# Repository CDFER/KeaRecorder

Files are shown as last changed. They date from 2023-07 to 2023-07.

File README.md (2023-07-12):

# KeaRecorder



Welcome to KeaRecorder! This device allows you to accurately record ground water temperature using the ESP32S2 microcontroller.
## Table of Contents

- [KeaRecorder](#kearecorder)
  - [Table of Contents](#table-of-contents)
  - [Overview](#overview)
  - [Main Hardware Components](#main-hardware-components)
  - [Usage](#usage)
  - [Installation](#installation)
  - [Configuration](#configuration)
  - [Contributing](#contributing)
  - [Other](#other)
  - [License](#license)

## Overview

KeaRecorder is an designed specifically for recording and monitoring ground water temperature. Here are some key features of KeaRecorder:

- Backup clock: The built-in backup clock ensures accurate timekeeping, even when far away from civilization, guaranteeing reliable temperature data.
- Timezone support: Customize the time display and recordings based on your location, allowing seamless integration into your local time zone.
- Wi-Fi time synchronization: KeaRecorder synchronizes its time through a Wi-Fi network time server, providing accurate time information for precise temperature monitoring.
- Low power consumption: With its energy-efficient design, KeaRecorder can operate for extended periods without draining the battery.
- Easy access to data: KeaRecorder emulates a USB drive through its USB-C port, simplifying access to temperature data stored on the SD card.

## Main Hardware Components

KeaRecorder utilizes high-quality hardware components to ensure optimal performance and reliability. Here are the main hardware components used:

- SLM6500 Lithium ion BMS: This Battery Management System ensures safe and efficient operation, managing power effectively.
- ESP32S2: The ESP32S2 microcontroller provides the necessary processing power and connectivity options, serving as the brain of KeaRecorder.
- MicroSD card (SPI): The SD card securely stores the recorded temperature data, offering ample storage capacity for monitoring needs.
- ST7789V3 IPS Display (SPI): The vibrant display module shows real-time temperature readings from the sensors in vivid detail.
- PCF8563 RTC (I2C): The Real-Time Clock (RTC) module enables precise timekeeping, ensuring accurate temperature records.
- 3 OneWire Busses with up to 5 DS18B20 Temperature Sensors on each: These temperature sensors allow monitoring of multiple areas or depths with ease and accuracy.

## Usage

Using KeaRecorder is easy and intuitive. Follow these steps to get started:

1. Power on the KeaRecorder unit by pressing the button to activate the display.
2. The display will show real-time temperature readings obtained from the sensors, providing instant insights into ground water temperature.
3. Press and hold the button to toggle the recording mode. This enables or disables the logging of temperature readings to the SD card at regular intervals, according to your needs.
4. Once recording is enabled, KeaRecorder will diligently capture and log temperature data, ensuring comprehensive records of ground water temperature fluctuations.
5. To access the recorded temperature data, either remove the SD card from KeaRecorder and insert it into a computer or connect KeaRecorder to a computer using a USB cable.





## Installation

Installing KeaRecorder is a straightforward process. Just follow these steps:

1. Clone the repository to your local machine to access the latest version of the code.
2. If you're using PlatformIO, the required libraries will be installed automatically. If not, make sure to manually install the necessary libraries.
3. Compile the code and upload it to the ESP32 device.

## Configuration

You can customize KeaRecorder using the following configuration options:

- WiFi Credentials: Update the `main.cpp` file with your WiFi network name and password to seamlessly integrate KeaRecorder into your existing network.
- Recording Interval: Adjust the `recordingIntervalMins` variable to set the desired interval for recording temperature readings. This allows you to tailor the device's logging frequency to your specific monitoring requirements.
- Time Zone: Modify the `time_zone` variable to establish the desired time zone, ensuring accurate time display and recording based on your location.

## Contributing

We welcome contributions from the community! Here's how you can contribute to the project's ongoing development:

1. Fork the repository to create a personal copy of the project.
2. Create a new branch dedicated to your feature or bug fix, ensuring focused and organized contributions.
3. Implement the necessary changes and commit your code, including clear and concise documentation.
4. Push the changes to your forked repository, making them available for further review and integration.
5. Submit a pull request to the main repository, allowing your contributions to be considered for inclusion in the project.

## Other

Special thanks to the exceptional team at @Espressif Systems for their remarkable work in developing this outstanding chip and seamlessly porting it to Arduino.

Made with passion and dedication by Chris Dirks (@cd_fer) in Aotearoa New Zealand.

## License

KeaRecorder is proudly licensed under the Hippocratic License HL3-CL-EXTR-FFD-MEDIA-MIL-MY-SV-TAL. For detailed licensing terms, please review the license file provided.

Feel free to reach out if you have any questions or need further assistance. Happy monitoring with KeaRecorder!

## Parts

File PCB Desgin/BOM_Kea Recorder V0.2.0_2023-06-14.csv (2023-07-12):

ID | Name | Designator | Footprint | Quantity | Manufacturer Part | Manufacturer | Supplier | Supplier Part | Price | Pins | JLCPCB Part Class | Contributor | Resistance (Ohms) | link
3 | 100nF | C1,C2,C7,C9,C13,C17,C22,C29,C30,C32,C33,C34,C35,C37,C38,C39 | C0402 | 16 | CL05B104KO5NNNC | SAMSUNG(三星) | LCSC | C1525 | 0.001 | 2 | Basic Part
4 | 10uF | C3,C5,C12,C14,C16,C18,C19,C21,C23,C40 | C0402 | 10 | CL05A106MQ5NUNC | SAMSUNG(三星) | LCSC | C15525 | 0.005 | 2 | Basic Part
5 | 22uF | C4 | C0603 | 1 | CL10A226MQ8NRNC | SAMSUNG(三星) | LCSC | C59461 | 0.01 | 2 | Basic Part
6 | 4.7uF | C6,C20,C24 | C0402 | 3 | CL05A475MP5NRNC | SAMSUNG(三星) | LCSC | C23733 | 0.006 | 2 | Basic Part
7 | 1uF | C8,C31,C36 | C0402 | 3 | CL05A105KA5NQNC | SAMSUNG(三星) | LCSC | C52923 | 0.004 | 2 | Basic Part
8 | 22pF | C15 | C0402 | 1 | 0402CG220J500NT | FH(风华) | LCSC | C1555 | 0.001 | 2 | Basic Part
9 | 4.7pF | C41 | C0402 | 1 | 0402CG4R7C500NT | FH(风华) | LCSC | C1569 | 0.001 | 2 | Basic Part
10 | 27pF | C42,C43 | C0402 | 2 | 0402CG270J500NT | FH(风华) | LCSC | C1557 | 0.001 | 2 | Basic Part
11 | 2.7pF | C44 | C0402 | 1 | 0402CG2R7C500NT | FH(风华) | LCSC | C1561 | 0.001 | 2 | Basic Part
12 | 1pF | C45 | C0402 | 1 | 0402CG1R0C500NT | FH(风华) | LCSC | C1550 | 0.001 | 2 | Basic Part
13 | SMF30CA | D1 | SOD-123FL_L2.8-W1.8-LS3.7-BI | 1 | SMF30CA | Liown(里阳半导体) | LCSC | C2990493 | 0.034 | 2 | Basic Part | lcsc |  | https://atta.szlcsc.com/upload/public/pdf/source/20220523/073C11711A077522E04B0931D8CF3CC3.pdf
14 | 1N5819WS | D2 | SOD-323_L1.8-W1.3-LS2.5-RD | 1 | 1N5819WS | Hottech(合科泰) | LCSC | C191023 | 0.014 | 2 | Basic Part | LCSC
15 | 1N4148 | D3 | SOD-323_L1.8-W1.3-LS2.5-RD | 1 | 1N4148WS | CJ(江苏长电/长晶) | LCSC | C2128 | 0.01 | 2 | Basic Part
16 | ZMM3V3 | D4 | LL-34_L3.5-W1.5-RD | 1 | ZMM3V3-M | ST(先科) | LCSC | C8056 | 0.012 | 2 | Basic Part
17 | SRV05-4-P-T7 | ESD1 | SOT-23-6_L2.9-W1.6-P0.95-LS2.8-BR | 1 | SRV05-4-P-T7 | PROTEK | LCSC | C85364 | 0.176 | 6 | Basic Part
18 | 2A Hold 4A Trip Resettable Fuse | F1,F2 | F0805 | 2 | SL0805200 | 台湾陆海 | LCSC | C70158 | 0.069 | 2 | Extended Part
19 | OWBUS1 | JST1 | CONN-SMD_4P-P1.00_DEALON_1.0-4PWB | 1 | 1.0-4PWB | DEALON(德艺隆) | LCSC | C2905006 | 0.035 | 6 | Extended Part | LCSC
20 | OWBUS2 | JST2 | CONN-SMD_4P-P1.00_DEALON_1.0-4PWB | 1 | 1.0-4PWB | DEALON(德艺隆) | LCSC | C2905006 | 0.035 | 6 | Extended Part | LCSC
21 | OWBUS3 | JST3 | CONN-SMD_4P-P1.00_DEALON_1.0-4PWB | 1 | 1.0-4PWB | DEALON(德艺隆) | LCSC | C2905006 | 0.035 | 6 | Extended Part | LCSC
22 | UART | JST4 | CONN-SMD_4P-P1.00_DEALON_1.0-4PWB | 1 | 1.0-4PWB | DEALON(德艺隆) | LCSC | C2905006 | 0.035 | 6 | Extended Part | LCSC
23 | 3.3uH, 6A | L1 | IND-SMD_L7.3-W6.8 | 1 | MCS0630-3R3MN2 | PSA(信昌电陶) | LCSC | C394166 | 0.051 | 2 | Extended Part | LCSC
24 | 3.9nH 300mA | L2,L3 | C0402 | 2 | SDCL1005C3N9STDF | Sunlord(顺络) | LCSC | C14033 | 0.003 | 2 | Basic Part
25 | 3.9nH | L4,L5 | C0402 | 2 | SDCL1005C3N9STDF | Sunlord(顺络) | LCSC | C14033 | 0.003 | 2 | Basic Part
26 | 1.47"-IPS-LCD-172X320-RGB | LCD1 | 1.47"-IPS-TFT-172X320-RGB | 1 |  |  | ZJY |  |  | 12 |  | Mingjie
27 | ESP32PWR | LDO1 | SOT-25-5_L3.0-W1.8-P0.95-LS3.0-BR | 1 | XC6220B331MR-G | TOREX(特瑞仕) | LCSC | C86534 | 0.368 | 5 | Extended Part
28 | IOPWR | LDO2 | SOT-25-5_L3.0-W1.8-P0.95-LS3.0-BR | 1 | XC6220B331MR-G | TOREX(特瑞仕) | LCSC | C86534 | 0.368 | 5 | Extended Part
29 | SPIPWR | LDO3 | SOT-25-5_L3.0-W1.8-P0.95-LS3.0-BR | 1 | XC6220B331MR-G | TOREX(特瑞仕) | LCSC | C86534 | 0.368 | 5 | Extended Part
30 | CHRG | LED1 | LED0603-RD | 1 | KT-0603R | null | LCSC | C2286 | 0.006 | 2 | Basic Part
31 | STDBY | LED2 | LED0603-RD | 1 | 19-217/GHC-YR1S2/3T | EVERLIGHT(亿光) | LCSC | C72043 | 0.027 | 2 | Basic Part
32 | OCP Fault | LED3 | LED0603-RD | 1 | KT-0603R | null | LCSC | C2286 | 0.006 | 2 | Basic Part
33 | TX | LED4 | LED0603-RD | 1 | 19-213/Y2C-CQ2R2L/3T(CY) | EVERLIGHT(亿光) | LCSC | C72038 | 0.023 | 2 | Basic Part
34 | RX | LED5 | LED0603-RD | 1 | 19-213/Y2C-CQ2R2L/3T(CY) | EVERLIGHT(亿光) | LCSC | C72038 | 0.023 | 2 | Basic Part
35 | UART_TX | LED6 | LED0603-RD | 1 | 19-213/Y2C-CQ2R2L/3T(CY) | EVERLIGHT(亿光) | LCSC | C72038 | 0.023 | 2 | Basic Part
36 | UART_RX | LED7 | LED0603-RD | 1 | 19-213/Y2C-CQ2R2L/3T(CY) | EVERLIGHT(亿光) | LCSC | C72038 | 0.023 | 2 | Basic Part
37 | 100k NTC Thermistor (B=4250) | NTC1 | R0402 | 1 | NCP15WF104F03RC | muRata(村田) | LCSC | C77130 | 0.013 | 2 | Extended Part
38 | AO3401A (PMOS) | Q1 | SOT-23_L2.9-W1.3-P1.90-LS2.4-BR | 1 | AO3401A | AOS | LCSC | C15127 | 0.042 | 3 | Basic Part
39 | 2N7002 | Q2 | SOT-23-3_L2.9-W1.3-P1.90-LS2.4-BR | 1 | 2N7002 | CJ(江苏长电/长晶) | LCSC | C8545 | 0.015 | 3 | Basic Part
40 | PNP (MMBT5401) | Q3 | SOT-23-3_L2.9-W1.3-P1.90-LS2.4-BR | 1 | MMBT5401 | CJ(江苏长电/长晶) | LCSC | C8326 | 0.015 | 3 | Basic Part | 立创EDA官方封装库
41 | 5.1kΩ | R1,R2 | R0402 | 2 | 0402WGF5101TCE | UNI-ROYAL(厚声) | LCSC | C25905 | 0.001 | 2 | Basic Part |  | 5.1K
42 | 10kΩ | R3,R9,R11,R14,R15,R16,R26,R27 | R0402 | 8 | 0402WGF1002TCE | UNI-ROYAL(厚声) | LCSC | C25744 | 0.001 | 2 | Basic Part |  | 10K
43 | 100kΩ | R4,R8,R10,R21,R22,R25,R28,R34,R39,R41 | R0402 | 10 | 0402WGF1003TCE | UNI-ROYAL(厚声) | LCSC | C25741 | 0.001 | 2 | Basic Part |  | 100K
44 | 100mΩ | R5,R7 | R1206 | 2 | 1206W4F100LT5E | UNI-ROYAL(厚声) | LCSC | C25334 | 0.007 | 2 | Basic Part |  | 0.1
45 | 150kΩ | R6 | R0402 | 1 | 0402WGF1503TCE | UNI-ROYAL(厚声) | LCSC | C25755 | 0.001 | 2 | Basic Part |  | 150K
46 | 1MΩ | R12,R13,R19,R20 | R0402 | 4 | 0402WGF1004TCE | UNI-ROYAL(厚声) | LCSC | C26083 | 0.001 | 2 | Basic Part |  | 1M
47 | 4.7kΩ | R17,R18 | R0402 | 2 | 0402WGF4701TCE | UNI-ROYAL(厚声) | LCSC | C25900 | 0.001 | 2 | Basic Part |  | 4.7K
48 | 0Ω | R23 | R0402 | 1 | 0402WGF0000TCE | UNI-ROYAL(厚声) | LCSC | C17168 | 0.001 | 2 | Basic Part |  | 0
49 | 470Ω | R24 | R0402 | 1 | 0402WGF4700TCE | UNI-ROYAL(厚声) | LCSC | C25117 | 0.001 | 2 | Basic Part |  | 470
50 | 47kΩ | R29,R30,R31,R32,R38,R40,R44,R45 | R0402 | 8 | 0402WGF4702TCE | UNI-ROYAL(厚声) | LCSC | C25792 | 0.001 | 2 | Basic Part |  | 47K
51 | 200Ω | R33 | R0402 | 1 | 0402WGF2000TCE | UNI-ROYAL(厚声) | LCSC | C25087 | 0.001 | 2 | Basic Part |  | 200
52 | 10Ω | R35 | R0402 | 1 | 0402WGF100JTCE | UNI-ROYAL(厚声) | LCSC | C25077 | 0.001 | 2 | Basic Part |  | 10
53 | 4.7kΩ | R36,R37,R42 | R0805 | 3 | 0805W8F4701T5E | UNI-ROYAL(厚声) | LCSC | C17673 | 0.002 | 2 | Basic Part |  | 4.7K
54 | 33kΩ | R43 | R0402 | 1 | 0402WGF3302TCE | UNI-ROYAL(厚声) | LCSC | C25779 | 0.001 | 2 | Basic Part |  | 33K
55 | TF-01A | SD1 | TF-SMD_TF-01A | 1 | TF-01A | 韩国韩荣 | LCSC | C91145 | 0.175 | 13 | Extended Part
56 | RESET | SW1 | KEY-SMD_4P-L4.2-W3.2-P2.20-LS4.6 | 1 |  |  |  |  |  | 4 |  | LCSC
57 | UP | SW2 | KEY-SMD_4P-L4.2-W3.2-P2.20-LS4.6 | 1 |  |  |  |  |  | 4 |  | LCSC
58 | DOWN | SW3 | KEY-SMD_4P-L4.2-W3.2-P2.20-LS4.6 | 1 |  |  |  |  |  | 4 |  | LCSC
59 | WAKE | SW4 | SW-TH_4P-L12.0-W12.0-P5.00-LS12.5-EH | 1 | SKHCBGA010 | ALPSALPINE(阿尔卑斯阿尔派) |  |  |  | 4 | Extended Part | LCSC
72 | GT-USB-7010ASV | U1 | USB-C-SMD_G-SWITCH_GT-USB-7010ASV | 1 | GT-USB-7010ASV | G-Switch(品赞) | LCSC | C2988369 | 0.079 | 16 | Extended Part | lcsc |  | https://atta.szlcsc.com/upload/public/pdf/source/20220407/276C2E8CEADC75D1A3BE3EA4074DCCE5.pdf
73 | SLM6500 | U2 | SOP-8_L4.9-W3.9-P1.27-LS6.0-BL-EP | 1 | SLM6500 | 无锡松朗微 | LCSC | C130315 | 0.241 | 9 | Extended Part | LCSC
74 | BWU.FL-IPEX1 | U3 | IPEX-SMD_BWIPX-1-001E | 1 | BWU.FL-IPEX1 | BAT WIRELESS(蝙蝠无线) | LCSC | C5137195 | 0.035 | 3 | Extended Part | lcsc |  | https://atta.szlcsc.com/upload/public/pdf/source/20220815/058ABE525AAE400925F1A3839AB872AC.pdf
75 | PCF8563T RTC | U4 | SOIC-8_L5.0-W4.0-P1.27-LS6.0-BL | 1 | PCF8563T/5,518 | NXP(恩智浦) | LCSC | C7440 | 0.485 | 8 | Basic Part
76 | ESP32-S2FN4R2 | U5 | QFN-56_L7.0-W7.0-P0.40-TL-EP4.0 | 1 | ESP32-S2FN4R2 | ESPRESSIF(乐鑫) | LCSC | C2844252 | 1.82 | 57 | Extended Part | LCSC
77 | 32.768kHz | X1 | FC-135R_L3.2-W1.5 | 1 | Q13FC1350000400 | EPSON(爱普生) | LCSC | C32346 | 0.199 | 2 | Basic Part
78 | 40MHz 15pF ±10ppm | X2 | CRYSTAL-SMD_4P-L3.2-W2.5-BL | 1 | S3240000151040 | JGHC(晶光华) | LCSC | C426990 | 0.065 | 4 | Extended Part | LCSC

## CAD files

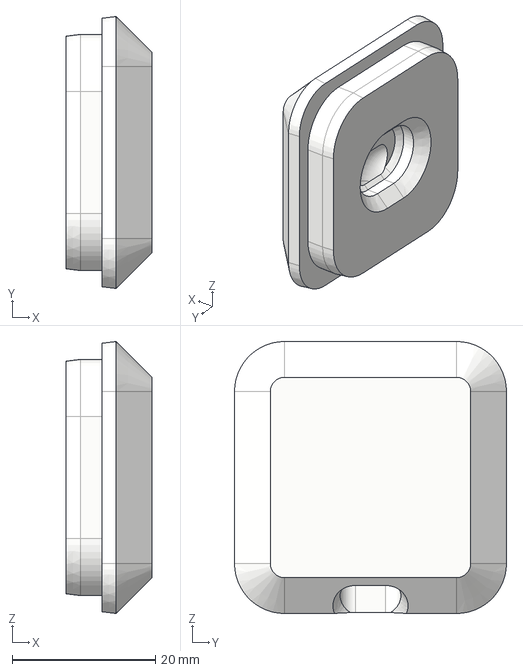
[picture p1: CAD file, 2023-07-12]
3D Printed Case/Connector v6.step
12.0 x 38.0 x 38.0 mm

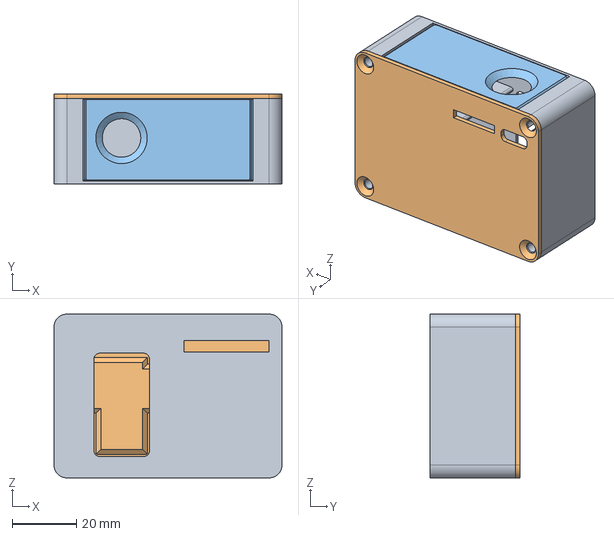
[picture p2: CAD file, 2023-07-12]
3D Printed Case/keaRecorder0.2.0 v22.step
71.0 x 28.1 x 51.0 mm

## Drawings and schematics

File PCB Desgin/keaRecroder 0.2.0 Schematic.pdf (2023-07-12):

# Lithium Battery Charger

# USB INPUT

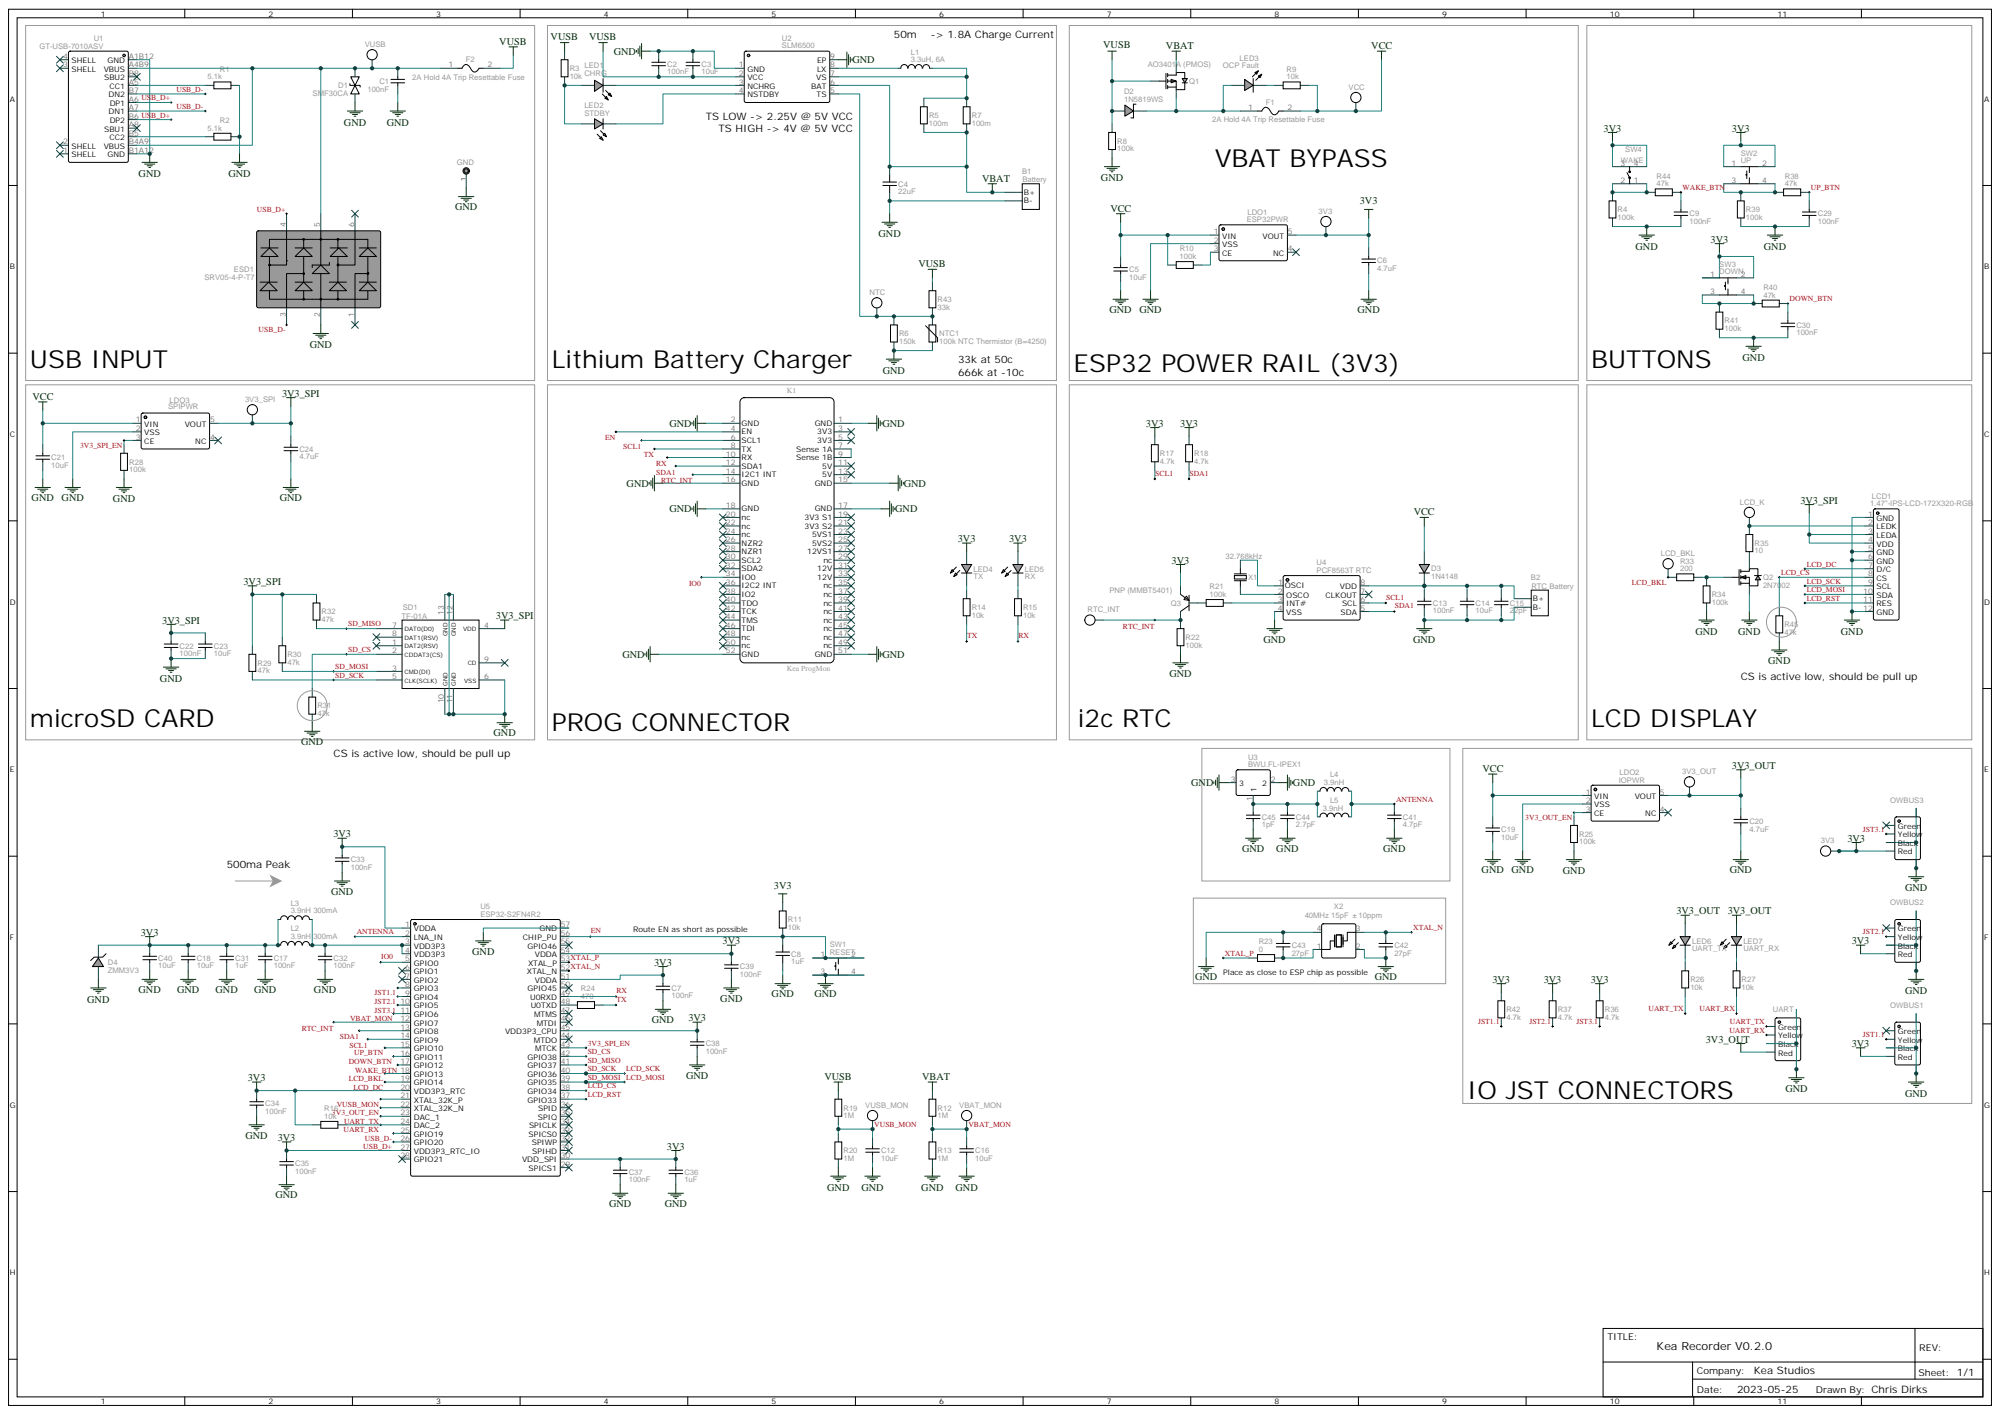
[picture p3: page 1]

2A Hold 4A Trip Resettable Fuse

GND
CS is active low, should be pull up

SPICS1 29 VDD_SPI 30 SPIHD 31 SPIWP 32 SPICS0 33 SPICLK 34 SPIQ 35 SPID 36 GPIO33 37 GPIO34 38 GPIO35 39 GPIO36 40 GPIO37 41 GPIO38 42 MTCK 43 MTDO 44 VDD3P3_CPU 45 MTDI 46 MTMS 47 U0TXD 48 U0RXD 49 GPIO45 50 VDDA 51 XTAL_N 52 XTAL_P 53 VDDA 54 GPIO46 55 CHIP_PU 56 GND 57

Place as close to ESP chip as possible

Drawn By: Chris Dirks

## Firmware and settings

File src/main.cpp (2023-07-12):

#include <Arduino.h>
#include <DallasTemperature.h>
#include <OneWire.h>
#include <SD.h>
#include <WiFi.h>
#include <tft_eSPI.h>

#include "USB.h"
#include "USBMSC.h"
#include "credentials.h"
#include "pcf8563.h"
#include "sntp.h"
#include "time.h"

#ifndef CREDENTIALS_H
#define CREDENTIALS_H

#define WIFI_WIFI_SSID "YourWIFI"
#define WIFI_PW "PASSWORD"

#endif

// Constants
constexpr uint8_t SCREEN_ON_TIME = 30;
constexpr uint16_t HOLD_DURATION = 3000;
constexpr uint8_t ONEWIRE_TEMP_RESOLUTION = 10;

const uint8_t batterySmoothingFactor = 5;	   // Example: 10 represents 10% of new value
const float temperatureSmoothingFactor = 0.5;  // Smaller values for slower response, larger values for faster response with more noise

// const char* time_zone = "NZST-12NZDT,M9.5.0,M4.1.0/3";
const char* time_zone = "CST6CDT,M3.2.0,M11.1.0";
constexpr uint32_t DEEPSLEEP_INTERUPT_BITMASK = (1UL << WAKE_BUTTON) | (1UL << VUSB_SENSE);
constexpr uint32_t RTC_DEEPSLEEP_INTERUPT_BITMASK = DEEPSLEEP_INTERUPT_BITMASK | (1UL << WIRE_RTC_INT);

// Ultra Global Variables (stored even in deep sleep)
RTC_DATA_ATTR uint16_t batteryMilliVolts = 0;
RTC_DATA_ATTR bool recording = false;
RTC_DATA_ATTR uint8_t recordingIntervalMins = 15;
RTC_DATA_ATTR char logFilePath[64];
RTC_DATA_ATTR char serialNumber[3];

// Global Variables
TFT_eSPI screen;
PCF8563_Class rtc;
bool systemTimeValid = false;
bool recordingDot = true;
bool sensorsChanged = false;

SemaphoreHandle_t buttonSemaphore;

USBMSC MSC;
USBCDC USBSerial;

auto configurePin = [](int pin, int mode, int initialState) {
	pinMode(pin, mode);
	digitalWrite(pin, initialState);
};

// For this to work with Espressif's ESP32 code you need to change line 694 esp32 / hardware / eps32 / 2.0.3 / libraries / SD / src / sd_diskio.cpp

static int32_t onWrite(uint32_t lba, uint32_t offset, uint8_t* buffer, uint32_t bufsize) {
	return SD.writeRAW((uint8_t*)buffer, lba) ? bufsize : -1;
}

static int32_t onRead(uint32_t lba, uint32_t offset, void* buffer, uint32_t bufsize) {
	return SD.readRAW((uint8_t*)buffer, lba) ? bufsize : -1;
}

static bool onStartStop(uint8_t power_condition, bool start, bool load_eject) {
	return true;
}

// Struct to hold information about a single temperature sensor
struct temperatureSensor {
	DeviceAddress address;
	float temperature;
	bool error;
};

// Struct to hold information about a temperature sensor bus
struct temperatureSensorBus {
	uint8_t numberOfSensors;
	uint8_t oneWirePin;
	OneWire oneWireBus;
	DallasTemperature dallasTemperatureBus;
	temperatureSensor sensorList[5];
	uint32_t color;
};

// Struct to hold information about the SD card
struct sdCard {
	uint16_t cardTotalMib;
	uint16_t cardUsedMib;
	const char* cardType;
	bool connected;
};

const uint8_t oneWirePortCount = 3;
RTC_DATA_ATTR temperatureSensorBus oneWirePort[oneWirePortCount];
RTC_DATA_ATTR sdCard microSDCard;

/**
 * @brief Extracts the first hex character from byte 1, 3, 5, and 7 of a DeviceAddress.
 *
 * This function takes a DeviceAddress, which is an array of bytes representing a device address,
 * and extracts the first hex character from bytes 1, 3, 5, and 7. The result is stored in a static
 * character array and returned. The result array is null-terminated.
 *
 * @param address The DeviceAddress from which to extract the hex characters.
 * @return A pointer to the static character array holding the extracted hex characters.
 */
char* deviceAddressTo4Char(const DeviceAddress& address) {
	static char result[5];	// Static array to hold the extracted hex characters
	result[4] = '\0';		// Null-terminate the result array

	// Define a lookup table for hex characters
	const char hexLookup[] = "0123456789ABCDEF";

	// Extract the hex characters from bytes 1, 3, 5, and 7
	result[0] = hexLookup[(address[1] >> 4) & 0x0F];
	result[1] = hexLookup[(address[3] >> 4) & 0x0F];
	result[2] = hexLookup[(address[5] >> 4) & 0x0F];
	result[3] = hexLookup[(address[7] >> 4) & 0x0F];

	return result;
}

/**
 * @brief Interrupt handler for the button press.
 *
 * This function is called when the button interrupt is triggered. It gives the button semaphore,
 * allowing the button task to proceed. It also yields to a higher priority task if necessary.
 */
void buttonInterrupt() {
	BaseType_t xHigherPriorityTaskWoken = pdFALSE;
	xSemaphoreGiveFromISR(buttonSemaphore, &xHigherPriorityTaskWoken);
	portYIELD_FROM_ISR(xHigherPriorityTaskWoken);
}

/**
 * @brief Get the current date and time as a formatted string.
 *
 * @param format The desired format of the date and time string.
 * @return The current date and time as a formatted string.
 */
const char* getCurrentDateTime(const char* format) {
	static char dateTime[32];
	time_t currentEpoch;
	time(&currentEpoch);
	struct tm* timeInfo = localtime(&currentEpoch);
	strftime(dateTime, sizeof(dateTime), format, timeInfo);
	return dateTime;
}

/**
 * @brief Sets up the next alarm based on the current time and recording interval.
 *
 * This function calculates the next alarm minute based on the current time and the specified
 * recording interval. If the current minute is not aligned with the recording interval, it
 * adjusts the alarm minute to align with the next interval. If the alarm minute exceeds 60,
 * it wraps around to the next hour. The alarm is then set using the calculated minute.
 * Additionally, the alarm, timer, and CLK are enabled, and a log message is printed.
 */
void setupNextAlarm() {
	RTC_Date currentTime = rtc.getDateTime();

	uint8_t alarmMinute = currentTime.minute;

	if (currentTime.minute % recordingIntervalMins != 0) {
		// The current minute is not aligned with the recording interval
		// Calculate the adjustment needed to align with the next interval
		alarmMinute += recordingIntervalMins - (currentTime.minute % recordingIntervalMins);
	} else {
		// The current minute is already aligned with the recording interval
		// Increment alarmMinute by the recording interval
		alarmMinute += recordingIntervalMins;
	}

	if (alarmMinute >= 60) {
		// Set alarmMinute to 0 to wrap around to the next hour
		alarmMinute = 0;
	}

	rtc.setAlarmByMinutes(alarmMinute);
	rtc.enableAlarm();
	rtc.disableTimer();
	rtc.disableCLK();

	ESP_LOGI("Setting Recording Alarm", "Next alarm: %u, Current minute: %u", alarmMinute, currentTime.minute);
}

/**
 * @brief Clears the RTC alarm.
 *
 */
void clearAlarm() {
	rtc.disableAlarm();
	rtc.disableTimer();
	rtc.disableCLK();
}

/**
 * @brief Gets the serial number based on the MAC address
 */
void getSerialNumber() {
	uint8_t mac[6];
	WiFi.macAddress(mac);
	sprintf(serialNumber, "%02X", mac[5]);
}

/**
 * @brief Generates a filename based on the current timestamp and MAC address.
 * @return The generated filename as a null-terminated string.
 */
void generateFilename() {
	// Get the serial number
	getSerialNumber();

	// Build the filename with leading forward slash
	snprintf(logFilePath, sizeof(logFilePath), "/%s_%s.csv", getCurrentDateTime("%Y-%b-%e-%H%M"), serialNumber);  // Format: /2023-Jun-23-2041_C8.csv

	File file = SD.open(logFilePath, FILE_WRITE, true);
	if (!file) {
		ESP_LOGW("generateFilename", "Failed to open file");
		return;
	}

	char header[128] = "Date(YYYY-MM-DD),Time(HH:MM),Battery(mV)";

	// Iterate over each temperature sensor bus
	for (uint8_t portIndex = 0; portIndex < oneWirePortCount; portIndex++) {
		if (oneWirePort[portIndex].numberOfSensors > 0) {
			// Iterate over each sensor on the current bus
			for (uint8_t sensorIndex = 0; sensorIndex < oneWirePort[portIndex].numberOfSensors; sensorIndex++) {
				// Convert the address to text
				char tempStr[8];
				snprintf(tempStr, sizeof(tempStr), ",%s", deviceAddressTo4Char(oneWirePort[portIndex].sensorList[sensorIndex].address));
				strcat(header, tempStr);
			}
		}
	}

	file.println(header);
	ESP_LOGD("", "%s", header);

	file.close();
}

/**
 * @brief Task that monitors the wake button and toggles recording mode.
 *
 * This task initializes the wake button pin, attaches an interrupt to detect rising edges,
 * and monitors the button state to toggle the recording mode. When the button is pressed
 * and held for a certain duration, the recording mode is toggled. If recording is enabled,
 * the next alarm is set. The task periodically checks the button state using a semaphore
 * and waits for interrupts to occur.
 *
 * @param parameter Pointer to the task parameters (not used in this implementation).
 */
void buttonTask(void* parameter) {
	// Initialize wake button pin and attach interrupt
	pinMode(WAKE_BUTTON, INPUT);
	attachInterrupt(digitalPinToInterrupt(WAKE_BUTTON), buttonInterrupt, RISING);

	buttonSemaphore = xSemaphoreCreateBinary();

	TickType_t lastWakeTime = xTaskGetTickCount();

	while (true) {
		if (xSemaphoreTake(buttonSemaphore, portMAX_DELAY) == pdTRUE) {
			if (digitalRead(WAKE_BUTTON) == HIGH) {
				vTaskDelay(pdMS_TO_TICKS(HOLD_DURATION));  // Delay for the hold duration

				if (digitalRead(WAKE_BUTTON) == HIGH) {
					if (recording) {
						recording = false;
						vTaskDelay(10000 / portTICK_PERIOD_MS);
					} else {
						recording = true;
						generateFilename();
						ESP_LOGI("Started New File", "%s", logFilePath);

						setupNextAlarm();
						vTaskDelay(10000 / portTICK_PERIOD_MS);
					}
				}
			} 
		}

		vTaskDelayUntil(&lastWakeTime, pdMS_TO_TICKS(10));	// Check every 10 milliseconds for interrupt semaphore
	}
}

/**
 * @brief Enters deep sleep mode based on battery voltage and recording status.
 *
 * If the battery voltage is above 3300 millivolts and recording is enabled, the function
 * enables deep sleep mode with RTC wakeup. Otherwise, it enables deep sleep mode with
 * wakeup triggered by user input. After setting up the wakeup mode, the function starts
 * the deep sleep process.
 */
void enterDeepSleep() {
	if ((batteryMilliVolts > 3300) && recording) {
		// Enable deep sleep mode with RTC wakeup
		esp_sleep_enable_ext1_wakeup(RTC_DEEPSLEEP_INTERUPT_BITMASK, ESP_EXT1_WAKEUP_ANY_HIGH);
		ESP_LOGV("Enter DeepSleep", "Waiting For RTC or user input");
	} else {
		// Enable deep sleep mode with wakeup triggered by user input
		esp_sleep_enable_ext1_wakeup(DEEPSLEEP_INTERUPT_BITMASK, ESP_EXT1_WAKEUP_ANY_HIGH);
		ESP_LOGI("Enter DeepSleep", "Waiting for user input");
	}

	// Start the deep sleep process
	esp_deep_sleep_start();

	// code here will never be run...
}

/**
 * @brief Updates the clock based on the current system time or using NTP servers.
 *
 * This function initializes the RTC module and syncs it to the system time if recording is enabled.
 * If recording is disabled or the system time is not valid, the function syncs the RTC using NTP servers.
 * The function also sets up the next alarm if recording is enabled and the RTC interrupt pin is in the HIGH state.
 */
void updateClock() {
	Wire.begin(WIRE_SDA, WIRE_SCL, 100000);
	rtc.begin(Wire);

	// Sync RTC to the system time if available
	if (rtc.syncToSystem()) {
		setenv("TZ", time_zone, 1);
		tzset();
		systemTimeValid = true;
	} else {
		ESP_LOGE("Time", "NOT VALID");
		systemTimeValid = false;
	}

	pinMode(WIRE_RTC_INT, INPUT);

	if (recording) {
		// Setup the next alarm if the RTC interrupt pin is in the HIGH state
		if (digitalRead(WIRE_RTC_INT) == HIGH) {
			setupNextAlarm();
		}
	} else {
		if (digitalRead(WIRE_RTC_INT) == HIGH) {
			clearAlarm();
		}

		if (!systemTimeValid) {
			// Sync RTC using WIFI and NTP servers if system time is not valid

			// Define the NTP servers to be used for time synchronization
			const char* ntpServer1 = "pool.ntp.org";
			const char* ntpServer2 = "time.nist.gov";
			const char* ntpServer3 = "time.google.com";

			// Set the SNTP operating mode to polling, and configure the NTP servers
			sntp_setoperatingmode(SNTP_OPMODE_POLL);
			sntp_setservername(0, ntpServer1);
			sntp_setservername(1, ntpServer2);
			sntp_setservername(2, ntpServer3);
			sntp_init();

			WiFi.begin(WIFI_SSID, WIFI_PW);

			// Wait until at least one NTP server is reachable
			while (!(sntp_getreachability(0) + sntp_getreachability(1) + sntp_getreachability(2) > 0)) {
				delay(10);
			}

			// Sync RTC to the real-time clock (RTC) of the ESP32
			rtc.syncToRtc();

			WiFi.disconnect();
		}
	}
}

/**
 * @brief Calculate battery percentage based on voltage using a lookup table.
 *
 * Lookup table for battery voltage in millivolts and corresponding percentage (based on PANASONIC_NCR_18650_B).
 * battery voltage 3300 = 3.3V, state of charge 22 = 22%.
 */
const uint16_t batteryDischargeCurve[2][12] = {
	{0, 3300, 3400, 3500, 3600, 3700, 3800, 3900, 4000, 4100, 4200, 9999},
	{0, 0, 13, 22, 39, 53, 62, 74, 84, 94, 100, 100}};

/**
 * @brief Calculate battery percentage based on voltage.
 *
 * @param batteryMilliVolts The battery voltage in millivolts.
 * @return The battery percentage as a null-terminated char array.
 */
const char* calculateBatteryPercentage(uint16_t batteryMilliVolts) {
	static char batteryPercentage[5];  // Static array to hold the battery percentage
	batteryPercentage[4] = '\0';	   // Null-terminate the array

	// Determine the size of the lookup table
	uint8_t tableSize = sizeof(batteryDischargeCurve[0]) / sizeof(batteryDischargeCurve[0][0]);

	// Initialize the percentage variable
	uint8_t percentage = 0;

	// Iterate through the lookup table to find the two lookup values we are between
	for (uint8_t index = 0; index < tableSize - 1; index++) {
		// Check if the battery voltage is within the current range
		if (batteryMilliVolts <= batteryDischargeCurve[0][index + 1]) {
			// Get the x and y values for interpolation
			uint16_t x0 = batteryDischargeCurve[0][index];
			uint16_t x1 = batteryDischargeCurve[0][index + 1];
			uint8_t y0 = batteryDischargeCurve[1][index];
			uint8_t y1 = batteryDischargeCurve[1][index + 1];

			// Perform linear interpolation to calculate the battery percentage
			percentage = static_cast<uint8_t>(y0 + ((y1 - y0) * (batteryMilliVolts - x0)) / (x1 - x0));
			break;
		}
	}

	// Convert the percentage to a char array
	snprintf(batteryPercentage, sizeof(batteryPercentage), "%u%%", percentage);

	return batteryPercentage;
}

/**
 * @brief Populates the provided sdCard struct with information about the connected SD card.
 *
 * @param cardInfo Reference to the sdCard struct to populate.
 */
void populateSDCardInfo(sdCard& cardInfo) {
	if (cardInfo.connected) {
		uint8_t cardType = SD.cardType();
		switch (cardType) {
			case CARD_NONE:
				cardInfo.cardType = "No SD card attached";
				break;
			case CARD_MMC:
				cardInfo.cardType = "MMC";
				break;
			case CARD_SD:
				cardInfo.cardType = "SDSC";
				break;
			case CARD_SDHC:
				cardInfo.cardType = "SDHC";
				break;
			default:
				cardInfo.cardType = "UNKNOWN";
				break;
		}

		cardInfo.cardTotalMib = static_cast<uint16_t>(SD.totalBytes() / (1024 * 1024));
		cardInfo.cardUsedMib = static_cast<uint16_t>(SD.usedBytes() / (1024 * 1024));

		// Log the SD card information
		ESP_LOGI("SD Card Info", "Type: %s, Total Size: %u MiB, Used Size: %u MiB",
				 cardInfo.cardType, cardInfo.cardTotalMib, cardInfo.cardUsedMib);

	} else {
		// If SD card mount failed, log a warning and set the connected flag to false
		ESP_LOGW("SD Card", "Mount Failed!");
		cardInfo.connected = false;
	}
}

/**
 * @brief Writes a line of data to the SD card.
 *
 * This function writes a line of data to the SD card, including timestamp, battery information,
 * and temperature readings from various sensors. It performs the following steps:
 *
 * - Initializes the SD card.
 * - Opens the log file in append mode.
 * - Checks if the file is empty and writes the header if needed.
 * - Retrieves the current timestamp.
 * - Formats the data line with timestamp, battery voltage, and temperature readings.
 * - Writes the data line to the log file.
 * - Closes the file.
 *
 * @note Before calling this function, make sure to set up the log file path.
 *
 * @note This function assumes the existence of global variables and data structures
 *       related to temperature sensors and battery information.
 *
 * @note Make sure to initialize the SD card library before calling this function.
 *
 */
void writeLineToSDcard() {
	// Configure pins
	configurePin(SPI_EN, OUTPUT, HIGH);
	configurePin(TFT_CS, OUTPUT, HIGH);
	configurePin(SD_CARD_CS, OUTPUT, HIGH);

	// Initialize SD card
	if (SD.begin(SD_CARD_CS)) {
		ESP_LOGI("SD Card", "Connected");

		// Open file in append mode
		File file = SD.open(logFilePath, FILE_APPEND, true);
		if (!file) {
			ESP_LOGW("writeLineToSDcard", "Failed to open file");
			return;
		}

		// Create a buffer to store the data line
		char dataLine[128];

		// Format the data line with current date and time, and battery voltage
		snprintf(dataLine, sizeof(dataLine), "%s,%u", getCurrentDateTime("%Y-%m-%d,%H:%M"), batteryMilliVolts);

		// Iterate through each temperature sensor bus
		for (uint8_t portIndex = 0; portIndex < oneWirePortCount; portIndex++) {
			temperatureSensorBus& bus = oneWirePort[portIndex];

			// Check if the current bus has sensors
			if (bus.numberOfSensors > 0) {
				// Iterate through each sensor on the current bus
				for (uint8_t sensorIndex = 0; sensorIndex < bus.numberOfSensors; sensorIndex++) {
					char tempStr[8];

					// Check if the current sensor has an error
					if (bus.sensorList[sensorIndex].error) {
						strcpy(tempStr, ",ERR");
					} else {
						// Get the temperature reading from ram
						float temperature = bus.sensorList[sensorIndex].temperature;
						snprintf(tempStr, sizeof(tempStr), ",%.1f", temperature);
					}

					// Append the temperature reading to the data line
					strcat(dataLine, tempStr);
				}
			}
		}

		// Write the data line to the csv file
		file.println(dataLine);
		file.close();

		// Log the data line
		ESP_LOGD("", "%s", dataLine);

	} else {
		ESP_LOGW("No SD Card", "");
	}
}

/**
 * @brief Updates the user interface (UI) display with the latest information.
 *
 * This function updates the UI display to reflect the current state of the system. It includes
 * updating the REC symbol if the system is in recording mode, displaying battery percentage,
 * temperature values for sensors, SD card information, and the current date and time.
 * The function utilizes specific positions and colors to ensure consistent and organized
 * presentation of the information on the screen.
 */
void updateScreen() {
	if (sensorsChanged) {
		screen.fillScreen(TFT_BLACK);
		sensorsChanged = false;
	}

	// Define positions for REC symbol
	const int REC_CIRCLE_X = 18;
	const int REC_CIRCLE_Y = 18;
	const int REC_TEXT_X = 34;
	const int REC_TEXT_Y = 8;

	// Update REC symbol if recording
	if (recording) {
		// Determine the circle color and text color
		uint16_t circleColor = TFT_RED;
		uint16_t backgroundColor = TFT_BLACK;

		// Update the circle and text based on the recordingDot value
		if (recordingDot) {
			// Draw filled circle for REC symbol
			screen.fillSmoothCircle(REC_CIRCLE_X, REC_CIRCLE_Y, 10, circleColor, backgroundColor);
		} else {
			// Clear the circle for REC symbol
			screen.fillCircle(REC_CIRCLE_X, REC_CIRCLE_Y, 12, backgroundColor);
		}

		// Draw the text for REC symbol
		screen.setTextColor(TFT_WHITE, backgroundColor, true);
		screen.drawString("REC", REC_TEXT_X, REC_TEXT_Y, 4);

		// Toggle the recordingDot value
		recordingDot = !recordingDot;
	} else {
		// Clear the circle for REC symbol
		screen.fillCircle(REC_CIRCLE_X, REC_CIRCLE_Y, 12, TFT_BLACK);
	}

	// Define positions for battery percentage and temperature values
	const int BATTERY_PERCENTAGE_X = 100;
	const int BATTERY_PERCENTAGE_Y = 8;
	const int TEMPERATURE_START_Y = 36;
	const int COLOR_BAR_X = 6;
	const int COLOR_BAR_WIDTH = 5;
	const int COLOR_BAR_SPACING = 22;
	const int DEVICE_ADDRESS_X = 12;
	const int TEMPERATURE_X = DEVICE_ADDRESS_X + (4 * 20);
	const int DEGREE_SYMBOL_X = TEMPERATURE_X + 50;

	// Set text color and background color for battery percentage and temperature values
	screen.setTextColor(TFT_WHITE, TFT_BLACK, true);

	// Draw Battery Percentage
	screen.drawString(calculateBatteryPercentage(batteryMilliVolts), BATTERY_PERCENTAGE_X, BATTERY_PERCENTAGE_Y, 4);

	// Draw Temperature Values
	uint8_t yPosition = TEMPERATURE_START_Y;

	for (uint8_t portIndex = 0; portIndex < oneWirePortCount; portIndex++) {
		uint8_t numberOfSensors = oneWirePort[portIndex].numberOfSensors;

		if (numberOfSensors > 0) {
			const uint16_t colorBarEndY = yPosition + (numberOfSensors - 1) * COLOR_BAR_SPACING + 20;
			screen.drawWideLine(COLOR_BAR_X, yPosition, COLOR_BAR_X, colorBarEndY, COLOR_BAR_WIDTH, oneWirePort[portIndex].color, TFT_BLACK);

			for (uint8_t sensorIndex = 0; sensorIndex < numberOfSensors; sensorIndex++) {
				screen.drawString(deviceAddressTo4Char(oneWirePort[portIndex].sensorList[sensorIndex].address), DEVICE_ADDRESS_X, yPosition, 4);
				screen.drawFloat(oneWirePort[portIndex].sensorList[sensorIndex].temperature, 1, TEMPERATURE_X, yPosition, 4);
				screen.drawString("`C", DEGREE_SYMBOL_X, yPosition, 4);

				yPosition += COLOR_BAR_SPACING;
			}

			yPosition += 13;
		}
	}

	// Define positions for SD card information and current date and time
	const int SD_CARD_INFO_X = 8;
	const int SD_CARD_INFO_Y = 285;
	const int DATE_TIME_X = 8;
	const int DATE_TIME_Y = 300;

	// Set text color and background color for SD card information
	screen.setTextColor(TFT_DARKGREY, TFT_BLACK, true);

	// Draw SD card and unit id information
	screen.setCursor(SD_CARD_INFO_X, SD_CARD_INFO_Y, 2);
	if (microSDCard.connected) {
		screen.printf("%u/%u MiB %s SN: %s", microSDCard.cardUsedMib, microSDCard.cardTotalMib, microSDCard.cardType, serialNumber);
	} else {
		screen.printf("No SD Card SN: %s", serialNumber);
	}

	// Draw current date and time
	screen.drawString(getCurrentDateTime("%e %b %Y %H:%M"), DATE_TIME_X, DATE_TIME_Y, 2);
}
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
void loop() {
	// Empty loop, not needed
	vTaskSuspend(NULL);
}

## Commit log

2023-05-28 Switch to board.json GPIO map
2023-05-29 added support for multiple temp sensors
2023-06-08 added 0.2.0 Board added wifi config to credentials.h
2023-06-09 RTC alarm added Rewrite State Machine Add 0.2.0 Board
2023-06-14 mimic usb drive bugfix oneWire Buses generated filenames bugfix battery curve switch to mib file sizes screen fade inout
    [main.cpp]
2023-06-15 added documentation added smoothing to inputs bugfix SD card
    [BOM_Kea Recorder V0.2.0_2023-06-14.csv, partitions.csv]
2023-07-12 V0.2.0 Bugfixes and finishing touches
    [Connector v6.step, keaRecorder0.2.0 v22.step]
